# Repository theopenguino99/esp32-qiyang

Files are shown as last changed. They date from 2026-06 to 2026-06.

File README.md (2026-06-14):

<div align="center">

crimp-ER — ESP32-C6 Firmware

**On-device firmware for the crimp-ER hangboard scale — ESP32-C6, HX711 load cell, OLED readout &amp; live force streaming over BLE.**

</div>

---

# ESP32-C6 Smart Load Cell

Firmware for an ESP32-C6 based digital scale. Reads an HX711 load cell, shows live
weight on a 1.3" OLED, streams readings over BLE, and supports on-device
calibration with 2 push buttons. It speaks the **Tindeq Progressor** BLE protocol,
so it works with the official Tindeq app as well as the companion web app. I initially wanted to create an IOS app but realised I have to pay a premium to enroll in the Apple Developer Program in order to make the app public, so I made a web app instead which is free. My motivation for creating this project was to practice my software and hardware skills, and to build a useful tool for climbers. My gripe about the tindeq progressor is that it is quite expensive for what essentially is just a load cell so I decided to make one of my own and learn some skills along the way. This project was also something to keep me busy while I undergo ACL surgery rehabilitation. 

I would like to thank Yu Jie for helping me 3D print the prototype enclosure. I also want to thank [@SergioGasquez](https://github.com/SergioGasquez) for giving advice to build the device. I took quite a bit of inspiration from his project [Crimpdeq](https://github.com/crimpdeq).

Some important firmware modifications I made was to use a C6 module instead of a C3 rust module because I wanted to learn how to use a C6 for other future projects as it is one of the more powerful boards by espressif. Also I am using the platformio manager and writing the main firmware in arduino code simple for other beginner to intermediate developers. I also added 2 buttons for user friendly calibration if ever the user does not want to use the webapp or tindeq app. Also I implemented an OLED screen to visualise a force graph. Some things that I can potentially do in the future is a flappy bird game displayed on the OLED. These design choices were made with the possibility of further improvement without re-printing the PCB in mind. 

## Hardware

| Peripheral | Connection |
|---|---|
| HX711 load cell | DT = GPIO11, SCK = GPIO10 |
| SH1106 OLED (I2C) | SDA = GPIO6, SCL = GPIO7, addr 0x3C |
| WS2812B RGB LED | GPIO8 (onboard) |
| Button 1 | GPIO2 (active-low, internal pullup) |
| Button 2 | GPIO3 (active-low, internal pullup) |

All hardware design files live in [`hardware/`](hardware/) — KiCad project,
gerbers (`hardware/fab/`), and the 3D-printable enclosure.

### PCB

Custom 2-layer board designed in KiCad ([`hardware/pcb_Crimp-ER.kicad_pcb`](hardware/pcb_Crimp-ER.kicad_pcb)).

| Front | Back | Actual|
|:-----:|:----:|:-----:|
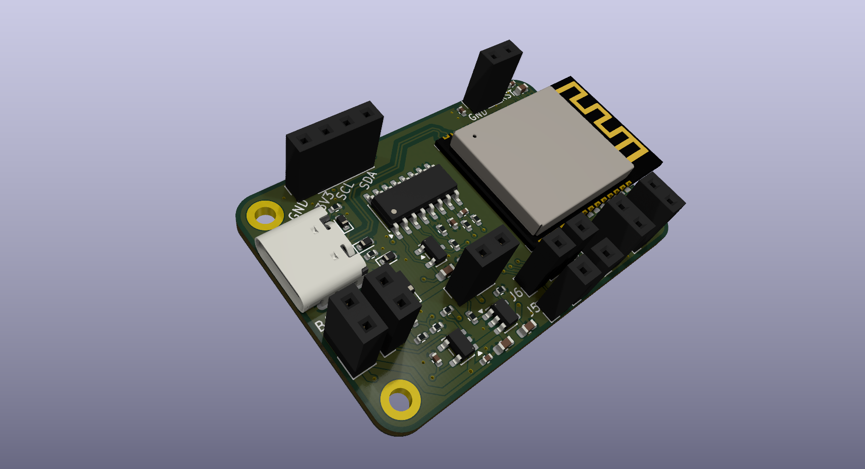
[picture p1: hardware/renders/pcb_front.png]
PCB front
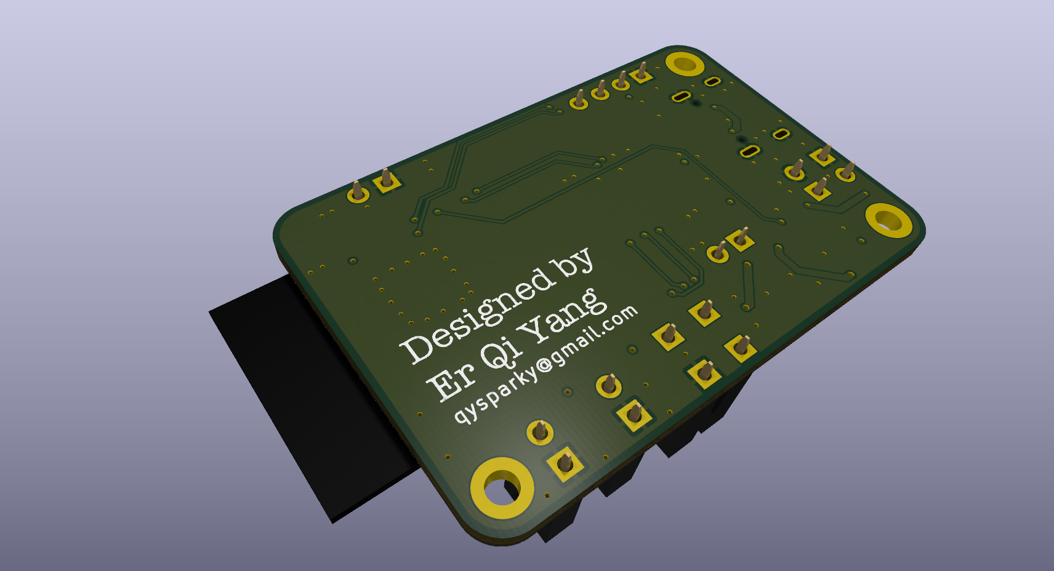
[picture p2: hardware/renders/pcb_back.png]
PCB back
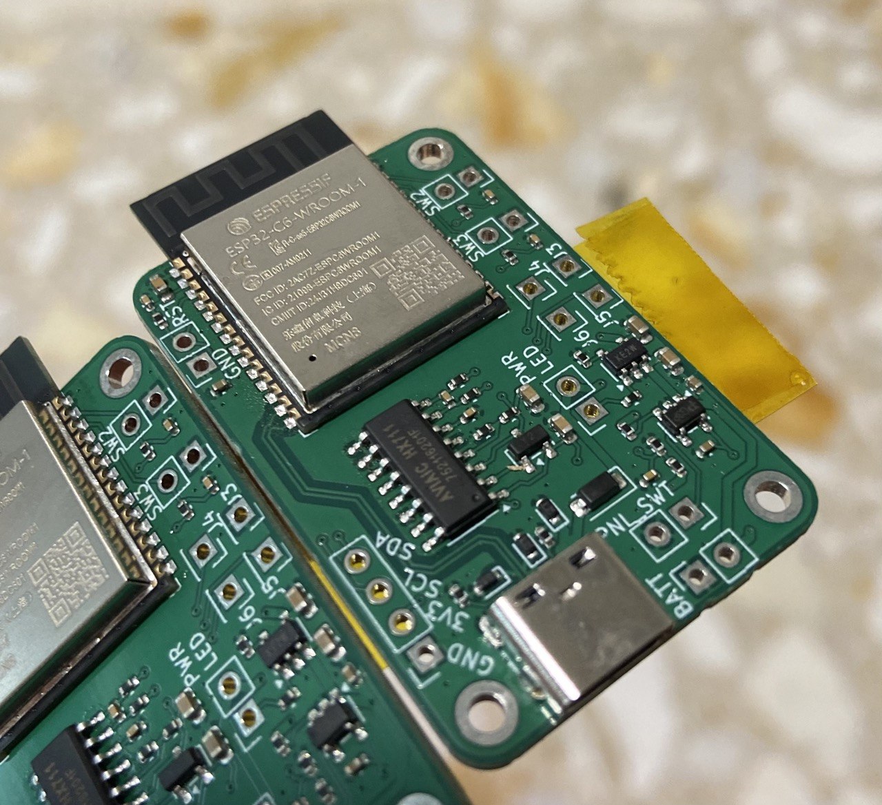
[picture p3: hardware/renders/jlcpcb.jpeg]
PCB actual
|  |  |  |

### Enclosure

Two-part 3D-printed case. Models (STL + STEP) live in
[`hardware/crimp-ER covers/`](hardware/crimp-ER%20covers/).

|Full Assembly| Top cover | Bottom cover |
|:---:|:---:|:-:|
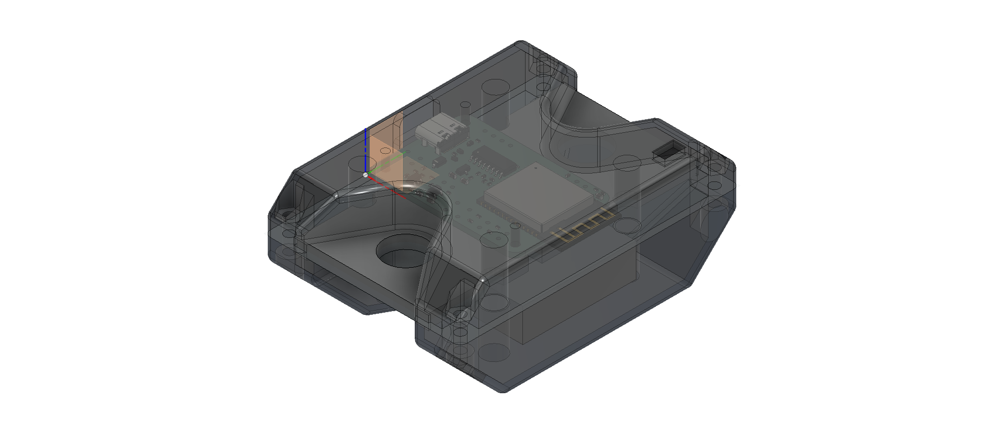
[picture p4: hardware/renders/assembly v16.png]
Full Assembly
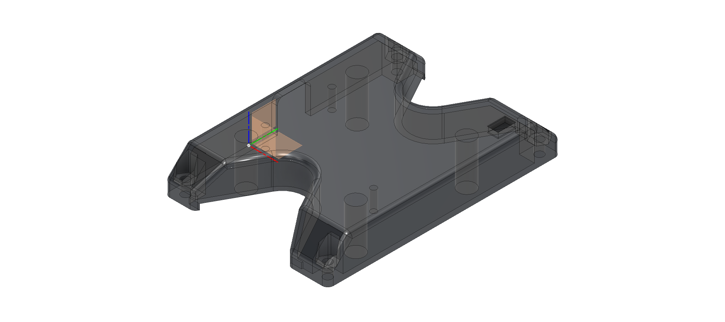
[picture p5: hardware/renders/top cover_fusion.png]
Top cover
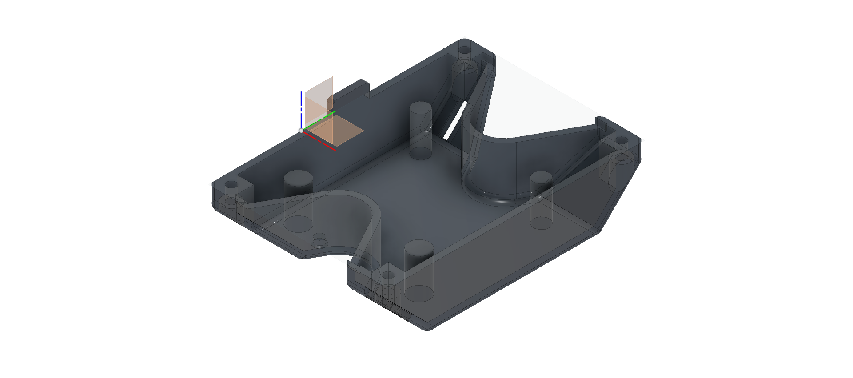
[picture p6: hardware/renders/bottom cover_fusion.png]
Bottom cover
||  |  |

> Print-ready downloads:
> [top STL](hardware/crimp-ER%20covers/top_cover.stl) ·
> [bottom STL](hardware/crimp-ER%20covers/bottom_cover.stl).

Two buttons drive the on-device UI: **Button 1 = change/skip**, **Button 2 =
OK/confirm**.

**On boot** the OLED shows a `CALIBRATE?` prompt and waits (no time limit) for a
choice:

- **Button 2** → run calibration (see below).
- **Button 1** → skip. If a calibration is saved, the device re-zeros the empty
  scale in memory (a boot tare that cancels power-on drift while keeping the saved
  scale factor); if none is saved, it warns and runs with defaults.

**Calibration**

1. *Pick the weight* — Button 1 cycles the reference-weight presets
   (1.25, 2.5, 5, 8, 10, 15, 20, 25 kg), Button 2 confirms. It starts at your
   last-used weight.
2. *Zero* — keep the scale empty; it samples the offset.
3. *Place weight* — a 30-second countdown appears (large timer + progress bar).
   Put the selected weight on the scale; Button 2 ends the countdown early.
4. The scale factor is computed and saved to flash (offset, scale, and the chosen
   weight), then a result screen shows (3 beeps on success, 1 on failure if the
   reading is invalid).

**Normal operation**

- OLED shows the current weight (large) plus a rolling history graph.
- The RGB LED flashes red while no BLE client is connected.
- Each changed reading is streamed over BLE as `"<weight> kg\n"`.

## BLE

The device advertises as **`Progressor_XXXX`** (`XXXX` derived from the chip MAC)
and exposes two services in parallel.

### Tindeq Progressor (works with the Tindeq app)

Emulates the Tindeq Progressor so the official **Tindeq app** can connect.

- Service: `7e4e1701-1ea6-40c9-9dcc-13d34ffead57`
- Data — notify, device → app: `7e4e1702-…`
- Control — write, app → device: `7e4e1703-…`
- **Weight stream** (little-endian): `[0x01][8][float32 kg][uint32 timestamp_µs]`,
  sent only between *start* and *stop*.
- **Commands:** tare `100`, start `101`, stop `102`, get app version `107`,
  get battery `111`. Tare is a soft, non-persisted re-zero (keeps the saved
  calibration factor).

### Nordic UART Service (web app)

- Service: `6E400001-…`, RX `6E400002-…`, TX `6E400003-…`
- Plain-text TX `"<weight> kg\n"`. Still running, so the companion web app works
  with no changes — it picks devices with `acceptAllDevices`, so the device simply
  shows up as `Progressor_XXXX` (instead of `ESP32-C6`) in the Bluetooth chooser.

A companion web app lives at `../esp32-qiyang-webapp`.

## Build & flash

```bash
pio run -t upload      # build + flash
pio device monitor     # serial @ 115200
pio run                # build only
```

## Licence

This project is dual-licensed by component:

- **Firmware** (`src/`, `include/`) — [MIT](LICENSE).
- **Hardware** (`hardware/`: PCB, gerbers, enclosure) —
  [CERN-OHL-S v2](hardware/LICENSE) (Strongly Reciprocal). See
  [hardware/README.md](hardware/README.md) for the notice.

In both cases please keep the copyright notice and credit theopenguino99.

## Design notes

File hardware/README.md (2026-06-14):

# Hardware

PCB and enclosure design files for the esp32-qiyang smart scale.

- `pcb_Crimp-ER.kicad_{pro,sch,pcb}` — KiCad project (schematic + layout).
- `fab/` — gerbers, drill files, pick-and-place, fabrication zip.
- `crimp-ER covers/` — 3D-printed enclosure (`*.stl` + `*.step`).
- `renders/` — PNG/JPEG previews.

## Licence

Copyright theopenguino99.

This hardware design is licensed under the CERN Open Hardware Licence
Version 2 - Strongly Reciprocal (CERN-OHL-S v2). You may redistribute and
modify it under the terms of that licence; you must keep this notice and
distribute the Complete Source of any conveyed modifications under the same
licence. See [LICENSE](LICENSE) for the full text, or
<https://cern.ch/cern-ohl> for more information.

This design is distributed WITHOUT ANY EXPRESS OR IMPLIED WARRANTY,
INCLUDING OF MERCHANTABILITY, SATISFACTORY QUALITY AND FITNESS FOR A
PARTICULAR PURPOSE. Please see section 6 of the licence for details.

> Note: this licence applies to the **hardware design files in this
> directory only**. The firmware (`src/`, `include/`) is licensed under MIT —
> see the [root LICENSE](../LICENSE).

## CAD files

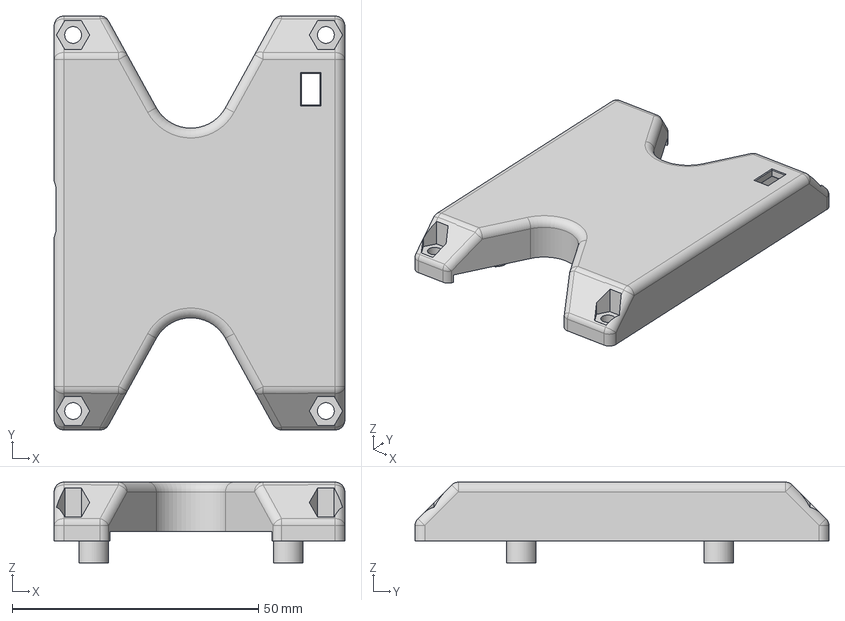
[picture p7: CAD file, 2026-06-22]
hardware/crimp-ER covers/top cover v2.step
59.0 x 84.0 x 16.4 mm

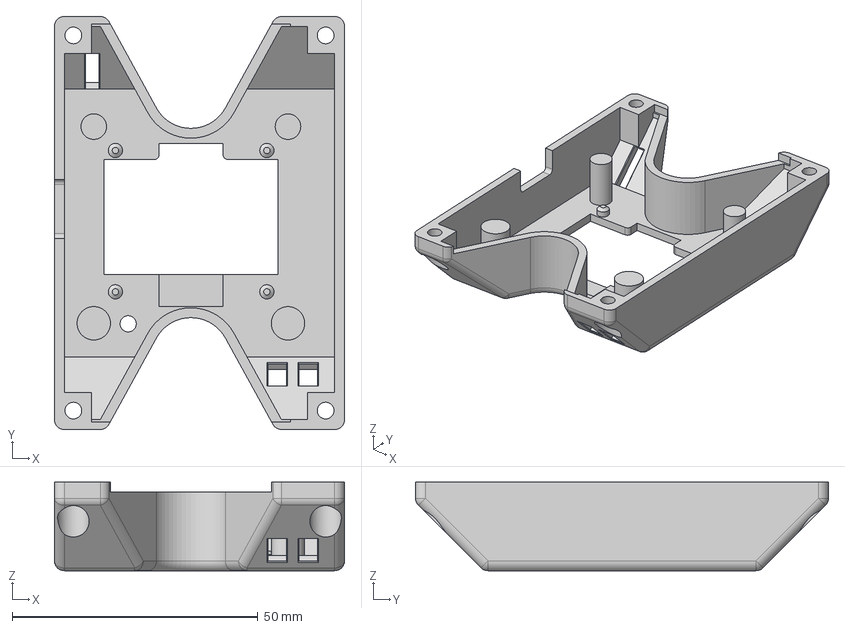
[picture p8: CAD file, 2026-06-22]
hardware/crimp-ER covers/bottom cover v2.step
59.0 x 84.0 x 18.0 mm

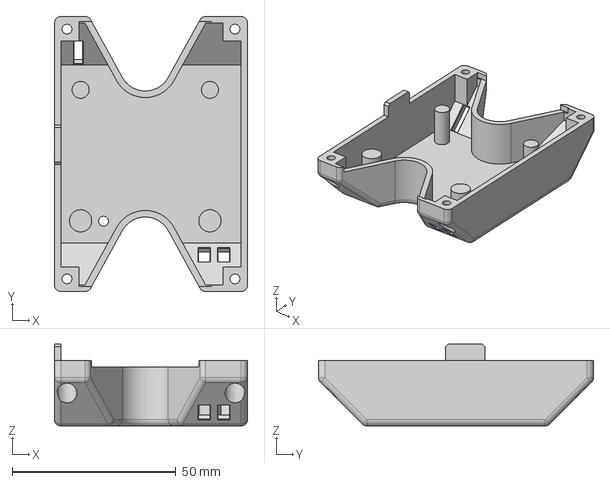
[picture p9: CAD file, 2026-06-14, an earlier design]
hardware/crimp-ER covers/bottom cover.step
59.0 x 84.0 x 25.0 mm

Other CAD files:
hardware/crimp-ER covers/top cover.step
hardware/crimp-ER covers/bottom cover v2.stl
hardware/crimp-ER covers/bottom_cover.stl
hardware/crimp-ER covers/top cover v2.stl
hardware/crimp-ER covers/top_cover.stl

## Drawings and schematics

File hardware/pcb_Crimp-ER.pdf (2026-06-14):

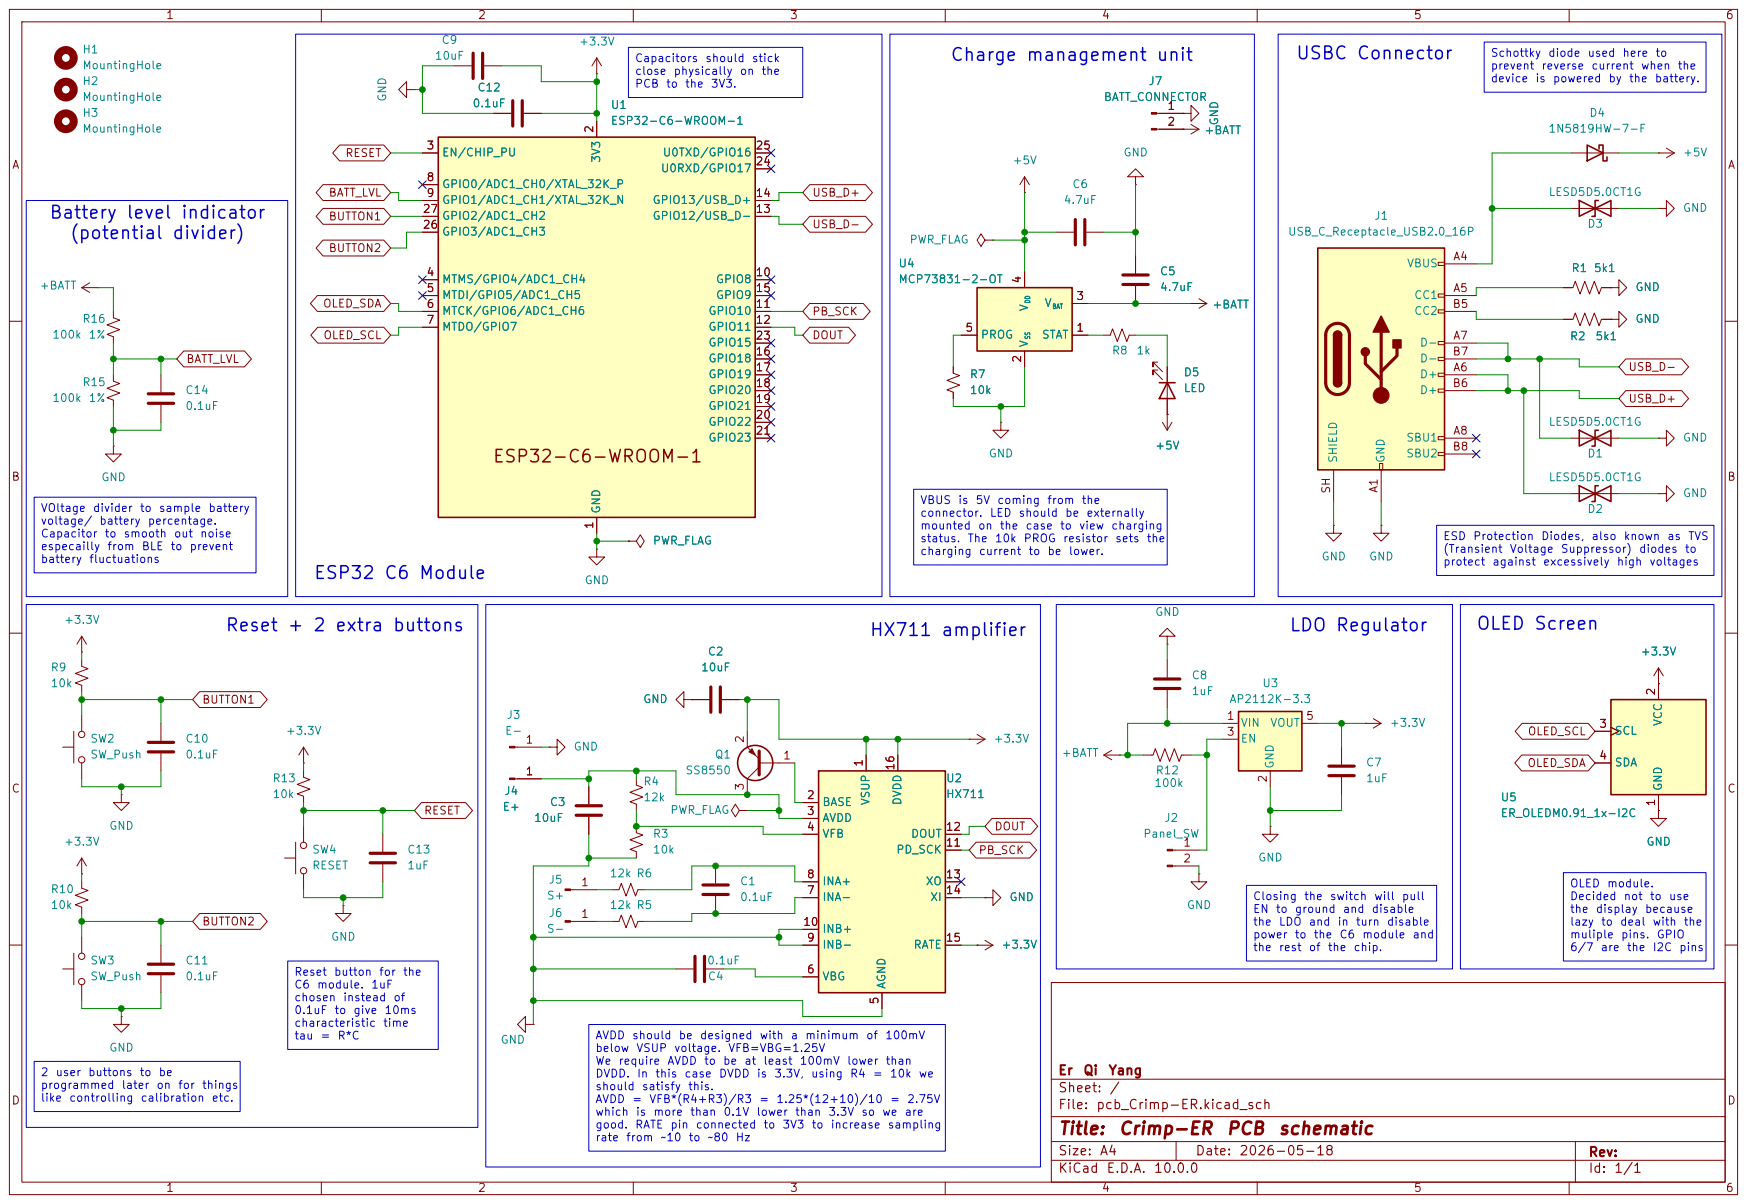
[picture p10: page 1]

prevent reverse current when the device is powered by the battery.

VBUS is 5V coming from the
connector. LED should be externally
mounted on the case to view charging
status. The 10k PROG resistor sets the

charging current to be lower. VOltage divider to sample battery
voltage/ battery percentage.
Capacitor to smooth out noise
especailly from BLE to prevent
SW_Push GND +3.3V

ESD Protection Diodes, also known as TVS
(Transient Voltage Suppressor) diodes to
protect against excessively high voltages

EN to ground and disable
the LDO and in turn disable power to the C6 module and

the display because
lazy to deal with the muliple pins. GPIO

the rest of the chip.

Reset button for the C6 module. 1uF

chosen instead of 0.1uF to give 10ms characteristic time

AVDD should be designed with a minimum of 100mV below VSUP voltage. VFB=VBG=1.25V We require AVDD to be at least 100mV lower than DVDD. In this case DVDD is 3.3V, using R4 = 10k we

2 user buttons to be programmed later on for things

should satisfy this. AVDD = VFB*(R4+R3)/R3 = 1.25*(12+10)/10 = 2.75V which is more than 0.1V lower than 3.3V so we are good. RATE pin connected to 3V3 to increase sampling

Er Qi Yang
Sheet: /
D Date: 2026-05-18 KiCad E.D.A. 10.0.0
File: pcb_Crimp-ER.kicad_sch
Title: Crimp-ER PCB schematic

like controlling calibration etc.

Size: A4 | Rev:

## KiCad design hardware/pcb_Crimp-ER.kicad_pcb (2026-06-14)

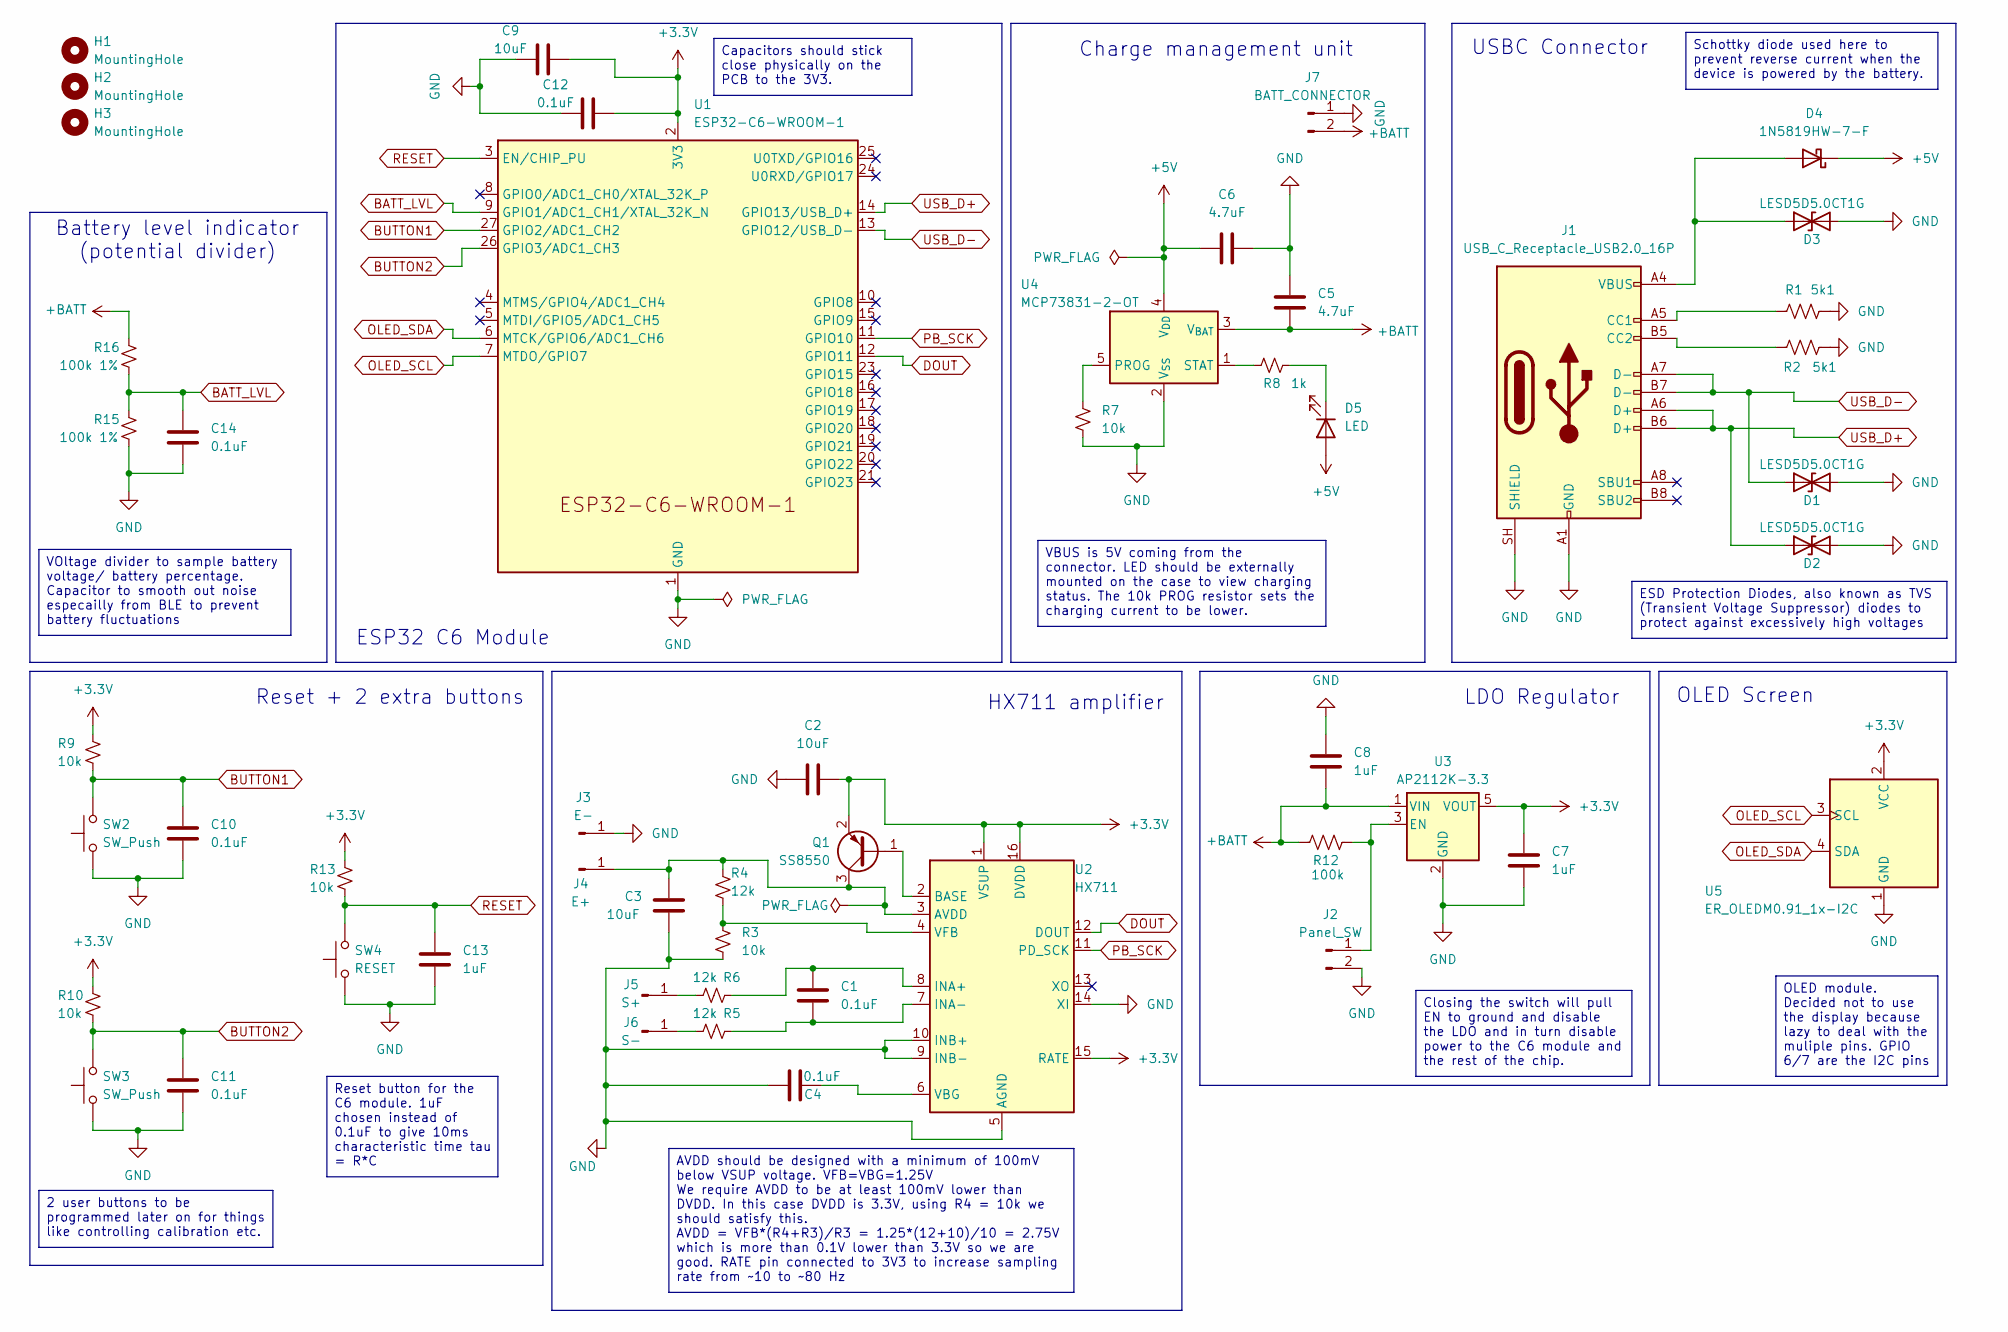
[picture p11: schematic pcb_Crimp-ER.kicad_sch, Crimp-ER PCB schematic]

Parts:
C1, C4, C10, C11, C12, C14: 0.1uF; C_0402_1005Metric
C2, C3, C9: 10uF; C_0603_1608Metric
C5, C6: 4.7uF; C_0603_1608Metric
C7, C8, C13: 1uF; C_0402_1005Metric
D1, D2, D3: LESD5D5.0CT1G; D_SOD-523
D4: 1N5819HW-7-F; D_SOD-123
D5: LED; PinSocket_1x02_P2.54mm_Vertical
H1, H2, H3: MountingHole; MountingHole_2.2mm_M2_DIN965_Pad
J1: USB_C_Receptacle_USB2.0_16P; USB_C_Receptacle_GCT_USB4105-xx-A_16P_TopMnt_Horizontal
J2: Panel_SW; PinSocket_1x02_P2.54mm_Vertical
J3: E-; PinSocket_1x01_P2.54mm_Vertical
J4: E+; PinSocket_1x01_P2.54mm_Vertical
J5: S+; PinSocket_1x01_P2.54mm_Vertical
J6: S-; PinSocket_1x01_P2.54mm_Vertical
J7: BATT_CONNECTOR; PinSocket_1x02_P2.54mm_Vertical
Q1: SS8550; SOT-23
R1, R2: 5k1; R_0402_1005Metric
R3, R7, R9, R10, R13: 10k; R_0402_1005Metric
R4, R5, R6: 12k; R_0402_1005Metric
R8: 1k; R_0402_1005Metric
R12: 100k; R_0402_1005Metric
R15, R16: 100k 1%; R_0402_1005Metric
SW2, SW3: SW_Push; PinSocket_1x02_P2.54mm_Vertical
SW4: RESET; PinSocket_1x02_P2.54mm_Vertical
U1: ESP32-C6-WROOM-1
U2: HX711; SOIC-16_3.9x9.9mm_P1.27mm
U3: AP2112K-3.3; SOT-23-5
U4: MCP73831-2-OT; SOT-23-5
U5: ER_OLEDM0.91_1x-I2C; PinSocket_1x04_P2.54mm_Vertical

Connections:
+3.3V: C2.2, C7.2, C9.1, C12.1, Q1.2 (E), R9.1, R10.1, R13.1, U1.2 (3V3), U2.1 (VSUP), U2.15 (RATE), U2.16 (DVDD), U3.5 (VOUT), U5.2 (VCC)
+5V: C6.2, D4.1 (K), D5.2 (A), U4.4 (V_{DD})
+BATT: C5.1, C8.1, J7.2, R12.1, R16.1, U3.1 (VIN), U4.3 (V_{BAT})
BATT_LVL: C14.1, R15.1, R16.2, U1.9 (GPIO1/ADC1_CH1/XTAL_32K_N)
BUTTON1: C10.1, R9.2, SW2.2, U1.27 (GPIO2/ADC1_CH2)
BUTTON2: C11.1, R10.2, SW3.2, U1.26 (GPIO3/ADC1_CH3)
DOUT: U1.12 (GPIO11), U2.12 (DOUT)
GND: C2.1, C3.2, C4.1, C5.2, C6.1, C7.1, C8.2, C9.2, C10.2, C11.2, C12.2, C13.2, C14.2, D1.2 (A2), D2.2 (A2), D3.2 (A2), J1.A1 (GND), J1.A12 (GND), J1.B1 (GND), J1.B12 (GND), J1.SH (SHIELD), J2.2, J3.1 (Pin_1_1), J7.1, R1.2, R2.2, R3.2, R7.2, R15.2, SW2.1, SW3.1, SW4.1, U1.1 (GND), U1.28 (GND), U1.29 (GND), U2.5 (AGND), U2.9 (INB-), U2.10 (INB+), U2.14 (XI), U3.2 (GND), U4.2 (V_{SS}), U5.1 (GND)
unnamed: D3.1 (A1), D4.2 (A), J1.A4 (VBUS), J1.A9 (VBUS), J1.B4 (VBUS), J1.B9 (VBUS)
unnamed: D5.1 (K), R8.2
unnamed: J1.A5 (CC1), R1.1
unnamed: J1.B5 (CC2), R2.1
unnamed: J2.1, R12.2, U3.3 (EN)
unnamed: C3.1, J4.1 (Pin_1_1), Q1.3 (C), R4.1, U2.3 (AVDD)
unnamed: J5.1 (Pin_1_1), R6.1
unnamed: J6.1 (Pin_1_1), R5.1
unnamed: Q1.1 (B), U2.2 (BASE)
unnamed: C1.1, R6.2, U2.8 (INA+)
unnamed: C1.2, R5.2, U2.7 (INA-)
unnamed: C4.2, U2.6 (VBG)
unnamed: R3.1, R4.2, U2.4 (VFB)
unnamed: R7.1, U4.5 (PROG)
unnamed: R8.1, U4.1 (STAT)
OLED_SCL: U1.7 (MTDO/GPIO7), U5.3 (SCL)
OLED_SDA: U1.6 (MTCK/GPIO6/ADC1_CH6), U5.4 (SDA)
PB_SCK: U1.11 (GPIO10), U2.11 (PD_SCK)
RESET: C13.1, R13.2, SW4.2, U1.3 (EN/CHIP_PU)
USB_D+: D2.1 (A1), J1.A6 (D+), J1.B6 (D+), U1.14 (GPIO13/USB_D+)
USB_D-: D1.1 (A1), J1.A7 (D-), J1.B7 (D-), U1.13 (GPIO12/USB_D-)

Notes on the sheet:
Reset + 2 extra buttons
LDO Regulator
HX711 amplifier
OLED Screen
ESP32 C6 Module
Battery level indicator (potential divider)
USBC Connector
Charge management unit
VBUS is 5V coming from the connector. LED should be externally mounted on the case to view charging status. The 10k PROG resistor sets the charging current to be lower.
2 user buttons to be programmed later on for things like controlling calibration etc.
Closing the switch will pull EN to ground and disable the LDO and in turn disable power to the C6 module and the rest of the chip.
AVDD should be designed with a minimum of 100mV below VSUP voltage. VFB=VBG=1.25V We require AVDD to be at least 100mV lower than DVDD. In this case DVDD is 3.3V, using R4 = 10k we should satisfy this. AVDD = VFB*(R4+R3)/R3 = 1.25*(12+10)/10 = 2.75V which is more than 0.1V lower than 3.3V so we are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
Schottky diode used here to prevent reverse current when the device is powered by the battery.
Reset button for the C6 module. 1uF chosen instead of 0.1uF to give 10ms characteristic time tau = R*C
ESD Protection Diodes, also known as TVS (Transient Voltage Suppressor) diodes to protect against excessively high voltages
OLED module. Decided not to use the display because lazy to deal with the muliple pins. GPIO 6/7 are the I2C pins
VOltage divider to sample battery voltage/ battery percentage. Capacitor to smooth out noise especailly from BLE to prevent battery fluctuations
Capacitors should stick close physically on the PCB to the 3V3.

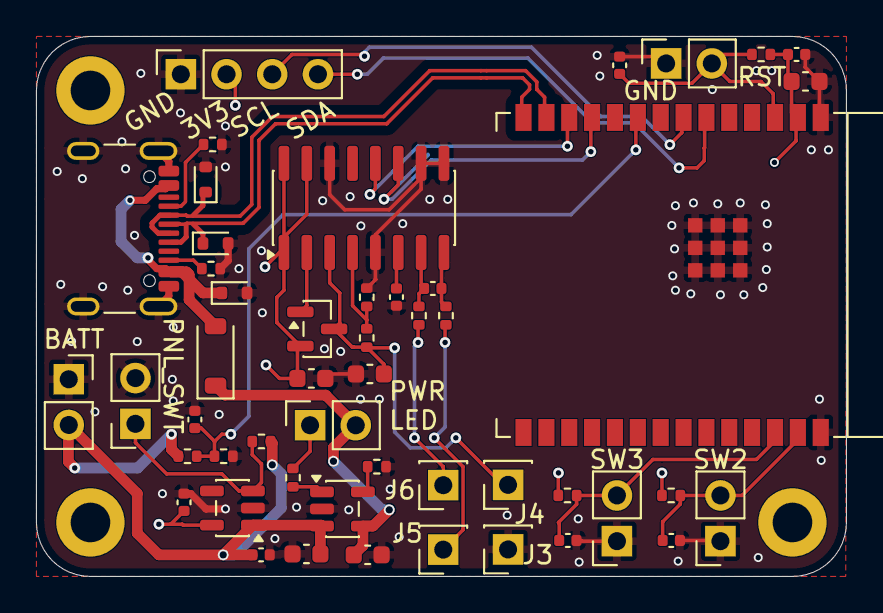
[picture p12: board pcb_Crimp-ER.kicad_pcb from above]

Board: 4 copper layers, 45.0 x 30.0 mm, 52 parts (0 on the bottom side), 29 nets.

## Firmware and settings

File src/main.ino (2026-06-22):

#include "app.h"

// ─── Setup ───────────────────────────────────────────────────────────────────
void setup() {
  pinMode(BUTTON1_PIN, INPUT_PULLUP);
  pinMode(BUTTON2_PIN, INPUT_PULLUP);
  pinMode(BUZZER_PIN, OUTPUT);

  // Battery ADC: 12-bit, 11dB attenuation (full ~0–3.1V range; divided Vbatt ≤ 2.1V)
  analogReadResolution(12);
  analogSetPinAttenuation(BATT_ADC_PIN, ADC_11db);
  updateBattery();   // prime batteryPct before the first display

  led.begin();
  led.setBrightness(50);
  led.setPixelColor(0, led.Color(0, 0, 0));
  led.show();

  Serial.begin(115200);
  unsigned long t0 = millis();
  while (!Serial && millis() - t0 < 3000);
  Serial.println("[BOOT] ESP32-C6 Load Cell + BLE");

  Wire.begin(OLED_SDA, OLED_SCL);
  if (!display.begin(OLED_ADDR, true)) {
    Serial.println("[BOOT] OLED init failed");
  }
  display.clearDisplay();
  display.display();

  scale.begin(HX711_DT_PIN, HX711_SCK_PIN);
  Serial.println("[BOOT] HX711 ready");

  bool hasCal = loadCalibration();

  // ── Calibration prompt — wait (no time limit) for the user to choose ──
  showCalibPrompt();
  bool doCalib = false;
  while (true) {
    if (buttonPressed(BUTTON2_PIN)) {     // BTN2 = calibrate
      waitButtonRelease(BUTTON2_PIN);
      doCalib = true;
      break;
    }
    if (buttonPressed(BUTTON1_PIN)) {     // BTN1 = skip
      waitButtonRelease(BUTTON1_PIN);
      break;
    }
    delay(50);
  }

  if (doCalib) {
    runCalibration();
  } else if (hasCal) {
    // Boot tare — refresh only the zero offset from the (empty) scale, in memory
    // only. The saved scale factor and offset in flash are left untouched, so the
    // previous calibration is preserved; this just cancels power-on zero drift.
    // Assumes the scale is empty at boot.
    showInfo("TARING", "Zeroing scale...", "Keep scale empty!", nullptr);
    delay(800);  // let the user clear the scale / readings settle
    calOffset = readRawAverage(CALIB_SAMPLES);
    Serial.print("[CAL] boot tare offset="); Serial.println(calOffset, 2);
  } else {
    Serial.println("[BOOT] no calibration saved — using defaults");
    calOffset = 0.0f;
    calScale  = 1.0f;
    showInfo("NO CALIBRATION", "Using defaults.", "Reboot & press BTN2", "to calibrate.");
    delay(3000);
  }

  bleSetup();
}

// ─── Loop ────────────────────────────────────────────────────────────────────
void loop() {
  if (!scale.is_ready()) { delay(10); return; }

  long  raw      = scale.read();
  float weightKg = medianFilteredKg(raw);   // spike-filtered, calibrated (low-lag)

  updateBattery();
  updateDisplay(weightKg);

  // ── Tindeq Progressor ──
  // Soft tare (re-zero) requested by the app — in-memory only, not persisted to
  // flash, so the saved 10 kg calibration scale factor is preserved.
  if (tindeqTareReq) {
    calOffset = readRawAverage(CALIB_SAMPLES);
    tindeqTareReq = false;
    Serial.println("[TQ] tared");
  }
  // Stream weight samples while a measurement is active.
  if (tindeqMeasuring) {
    tindeqNotifyWeight(weightKg, (uint32_t)(micros() - measureStartMicros));
  }

  static long lastRaw = LONG_MIN;
  if (deviceConnected && raw != lastRaw) {
    lastRaw = raw;
    String data = String(weightKg, 2) + " kg\n";
    pTxChar->setValue(data.c_str());
    pTxChar->notify();
    Serial.print("[TX] "); Serial.print(data);
  }

  if (!deviceConnected) {
    uint8_t flash = (millis() / 25) % 2;
    led.setPixelColor(0, flash ? led.Color(255, 0, 0) : led.Color(0, 0, 0));
    led.show();
  }
}

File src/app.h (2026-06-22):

#pragma once

// Single shared header for the whole firmware. Each .cpp includes just this
// file; it provides every constant, shared object, shared variable, and
// function prototype the modules need to see each other.

#include <Arduino.h>
#include <Wire.h>
#include <limits.h>
#include <string.h>
#include <math.h>
#include <Adafruit_NeoPixel.h>
#include <Adafruit_SH110X.h>
#include <HX711.h>
#include <Preferences.h>
#include <NimBLEDevice.h>

// ─── Pins ────────────────────────────────────────────────────────────────────
#define LED_PIN       8
#define NUM_LEDS      1
#define BUZZER_PIN    9
#define HX711_DT_PIN  11
#define HX711_SCK_PIN 10
#define BUTTON1_PIN   2
#define BUTTON2_PIN   3
#define BATT_ADC_PIN  1    // GPIO1 / ADC1_CH1 — battery sense (100k/100k divider, Vbatt = 2*Vadc)

// ─── OLED — SH1106 1.3" 128×64 ───────────────────────────────────────────────
#define OLED_ADDR   0x3C
#define OLED_WIDTH  128
#define OLED_HEIGHT 64
#define OLED_RESET  -1
#define OLED_SDA    6
#define OLED_SCL    7
#define OLED_UPDATE_MS 50   // 50ms refresh (cherry-picked from oled-display)

// ─── BLE (Nordic UART Service) — kept for the web app ────────────────────────
#define NUS_SERVICE_UUID "6E400001-B5A3-F393-E0A9-E50E24DCCA9E"
#define NUS_RX_UUID      "6E400002-B5A3-F393-E0A9-E50E24DCCA9E"
#define NUS_TX_UUID      "6E400003-B5A3-F393-E0A9-E50E24DCCA9E"

// ─── Tindeq Progressor BLE protocol — lets the official Tindeq app connect ────
// All multi-byte values are little-endian (ESP32 native), so float/uint32 can
// be memcpy'd straight into the packet.
#define TINDEQ_SERVICE_UUID "7e4e1701-1ea6-40c9-9dcc-13d34ffead57"
#define TINDEQ_DATA_UUID    "7e4e1702-1ea6-40c9-9dcc-13d34ffead57" // notify: device -> app
#define TINDEQ_CTRL_UUID    "7e4e1703-1ea6-40c9-9dcc-13d34ffead57" // write:  app -> device
// Control-point command opcodes (app -> device)
#define TINDEQ_CMD_TARE        100
#define TINDEQ_CMD_START_MEAS  101
#define TINDEQ_CMD_STOP_MEAS   102
#define TINDEQ_CMD_GET_APP_VER 107
#define TINDEQ_CMD_ENTER_SLEEP 110
#define TINDEQ_CMD_GET_BATT    111
// Notification response codes (device -> app)
#define TINDEQ_RES_CMD     0x00  // command response (battery / version / ...)
#define TINDEQ_RES_WEIGHT  0x01  // weight sample: float32 kg + uint32 timestamp_us

// ─── Calibration ─────────────────────────────────────────────────────────────
#define CALIB_WEIGHT_KG   10.0f  // default reference weight; user-selectable at calibration
#define CALIB_SAMPLES     10
#define CALIB_COUNTDOWN_S 30     // seconds to place known weight
#define DEBOUNCE_MS       50

// ─── Signal filtering ────────────────────────────────────────────────────────
// Median window rejects impulsive spikes with ~no lag — applied to every consumer
// (display + BLE), so it won't distort Tindeq RFD. The display EMA is extra
// smoothing for the OLED readout/graph ONLY; the BLE streams stay unfiltered by it.
#define FILTER_MEDIAN_WINDOW 3      // odd; raw samples kept for the running median
#define DISPLAY_EMA_ALPHA    0.2f   // OLED-only smoothing (0..1; higher = snappier, less smooth)

// ─── Battery monitor — GPIO1/ADC1_CH1 via a 100k/100k divider (Vbatt = 2*Vadc) ─
#define BATT_FULL_MV   4200   // 1S LiPo fully charged (CC/CV terminates at 4.2V) → 100%
#define BATT_EMPTY_MV  3500   // AP2112K-3.3 brown-out floor (3.3V + ~200mV dropout) → 0%
#define BATT_READ_MS   2000   // sampling cadence
#define BATT_SAMPLES   8      // ADC reads averaged per update

// ─── Shared peripheral objects (hardware.cpp) ────────────────────────────────
extern Adafruit_NeoPixel led;
extern Adafruit_SH1106G  display;
extern HX711             scale;
extern Preferences       prefs;

// ─── Input (input.cpp) ───────────────────────────────────────────────────────
bool buttonPressed(int pin = BUTTON1_PIN);   // debounced active-low read
void waitButtonRelease(int pin = BUTTON1_PIN);
void beepCount(int n);

// ─── Battery (battery.cpp) ───────────────────────────────────────────────────
extern uint32_t batteryMv;   // measured battery voltage (mV)
extern int      batteryPct;  // 0..100, derived from batteryMv
void updateBattery();

// ─── Calibration (calibration.cpp) ───────────────────────────────────────────
// Model: weightKg = (raw - calOffset) * calScale. Persisted to flash
// (Preferences namespace "hx711", keys "offset"/"scale"/"calwt").
extern float calOffset;
extern float calScale;
extern float calWeight;      // selected reference weight, persisted to flash
bool  loadCalibration();     // true if offset+scale were found in flash
void  saveCalibration();
float readRawAverage(int samples);
void  selectCalibWeight();   // weight-preset chooser (blocking, boot-only)
void  runCalibration();      // full boot calibration flow
float medianFilteredKg(long raw);  // running median of raw counts → calibrated kg (spike rejection)

// ─── OLED screens (ui.cpp) ───────────────────────────────────────────────────
void showCalibPrompt();
void showInfo(const char* title, const char* line1,
              const char* line2 = nullptr, const char* line3 = nullptr);
void showCountdown(int secsLeft);
void showCalibResult(bool ok);
void showCalWeightSelect(float w);
void updateDisplay(float weightKg);

// ─── BLE services (ble_service.cpp) ──────────────────────────────────────────
extern bool deviceConnected;            // a central is connected (NUS gate)
extern NimBLECharacteristic* pTxChar;   // NUS TX notify characteristic
extern bool          tindeqMeasuring;   // streaming between START(101)/STOP(102)
extern bool          tindeqTareReq;     // TARE(100) requested, serviced in loop()
extern unsigned long measureStartMicros;// micros() at START, for sample timestamps
void tindeqNotifyWeight(float kg, uint32_t tsMicros);
void bleSetup();

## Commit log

2026-04-20 feat: map load cell pressure to LED
2026-04-23 debug: broadcast name settings
    Explicitly include ESP32-C6 name so that the webapp can view the device
2026-05-11 feat: implement load cell calibration and buzzer feedback
    [main.ino]
2026-05-11 feat: enhance OLED display functionality and add I2C initialization
2026-06-01 Added images of 3D kicad design
2026-06-13 fix: re-tare zero offset at boot to cancel power-on drift
    On a normal boot (no recalibration) the firmware previously used the
    stored calOffset, so the unloaded reading sat at a stale, drifted zero.
    Now, when a saved calibration exists, refresh only calOffset from the
    empty scale in memory — the persisted scale factor and offset are left
    untouched, preserving the previous calibration.
    [main.ino]
2026-06-13 feat: add button2 functionality for calibration and weight selection
2026-06-13 feat: add 8kg preset and remove calibration prompt timeout
    - Add 8 kg to the calibration-weight presets.
    - Replace the 5s auto-skip countdown with an indefinite wait: the boot
    prompt now stays until the user presses BTN2 (calibrate) or BTN1 (skip),
    giving unlimited time to decide. Drops the now-unused CALIB_PROMPT_MS.
    [main.ino]
2026-06-14 feat: update .gitignore for KiCad files and add new directories for hardware assets
2026-06-14 Refactor code structure for improved readability and maintainability
    [bottom cover.step, bottom_cover.stl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]
2026-06-14 feat: update documentation and add hardware design files for buttons and enclosure
2026-06-14 feat: enhance calibration process and update README for two-button functionality
2026-06-14 feat: implement battery monitoring and display indicator
2026-06-22 Add new STL file for top cover v2 of crimp-ER covers
    [bottom cover v2.step, bottom cover v2.stl, top cover v2.step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]
2026-06-22 chore: update platformio.ini to pin upload and monitor ports for USB communication
2026-06-22 Add calibration functionality and UI improvements
    - Implement calibration logic in `calibration.cpp` for offset and scale adjustments.
    - Create `hardware.cpp` to initialize hardware components including LED, display, and scale.
    - Move button handling functions to `input.cpp` for better organization.
    - Refactor main loop in `main.ino` to utilize new setup functions and improve readability.
    - Introduce `ui.cpp` for display-related functions, enhancing the user interface for calibration prompts and weight displays.
    - Implement history tracking for weight measurements in the display.
    [bottom cover v2.step, bottom cover v2.stl, top cover v2.step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]
2026-06-22 Add median filtering and EMA smoothing for weight readings
